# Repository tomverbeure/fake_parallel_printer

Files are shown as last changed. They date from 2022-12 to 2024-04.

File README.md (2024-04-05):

# Fake Parallel Printer

This repo contains the design files for the Fake Printer tool: a hardware
dongle with a DB-25 connector that plugs into the parallel printer port
that was available on nearly all computers and equipment in the eighties
and nineties.

Check out this blog post for a detailed description of the design,
and build and usage instructions:

* [Fake Parallel Printer - A Parallel Port Traffic Capturing Tool](https://tomverbeure.github.io/2023/01/24/Fake-Parallel-Printer-Capture-Tool-HW.html)

There are 2 versions of the PCB. Revision 2 only uses 2 layers and doesn't
stick out as much out of the device in which is plugged in. It's probably
the best one to build. The firmware is designed to work for both PCB versions.

## PCB v1

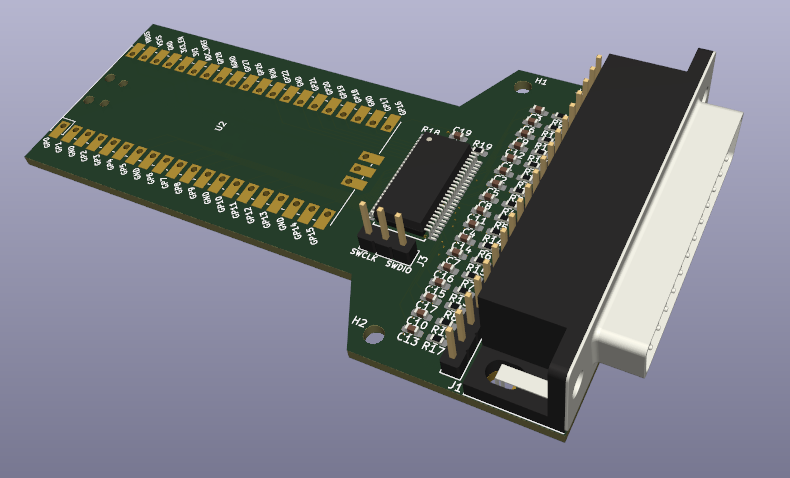
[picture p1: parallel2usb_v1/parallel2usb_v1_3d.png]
3D render of PCB v1


* KiCAD database of the PCB: [`./parallel2usb_v1`](./parallel2usb_v1)
* [Schematic of PCB v1](./parallel2usb_v1/parallel2usb_v1_schematic.pdf)

## PCB v2

**WARNING: v2 hasn't been tested!!!**

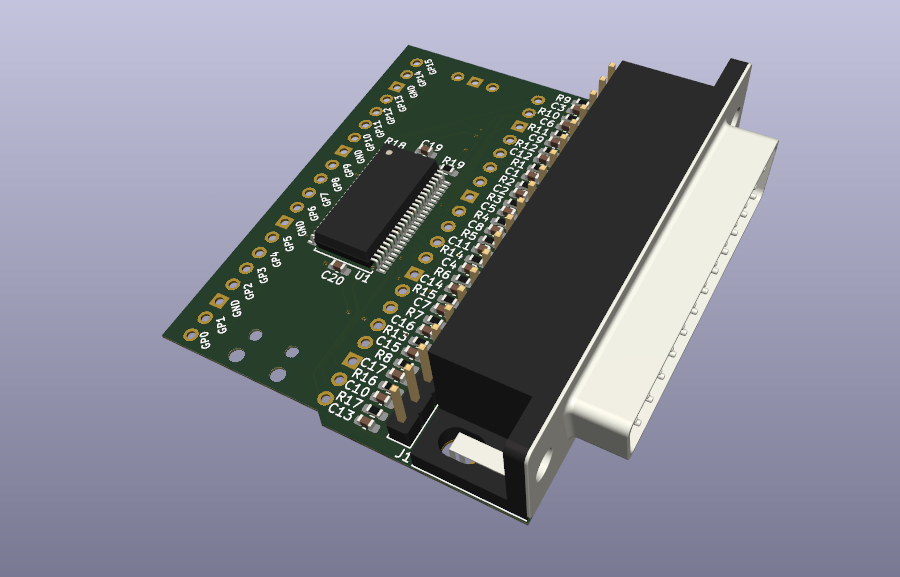
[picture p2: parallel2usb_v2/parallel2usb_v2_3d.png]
3D render of PCB v2


* KiCAD database of the PCB: [`./parallel2usb_v2`](./parallel2usb_v2)
* [Schematic of PCB v2](./parallel2usb_v2/parallel2usb_v2_schematic.pdf)

A Digikey cart with all the components to populate version 2 of the PCB can
be found [here](https://www.digikey.com/short/mcb8vf27). Not all
resistors and capacitor must be populated though. Check out the blog
post for details.

## Firmware

[`parallel2usb_hd_on.uf2`](parallel2usb_hd_on.uf2) contains the compiled
firmware for the Raspberry Pico.

To make changes and recompile yourself:

* set the `PICO_SDK` environment variable to the path of your locally installed 
  [Raspberry Pico SDK](https://github.com/raspberrypi/pico-sdk).
* Build the code:

      mkdir -p ./c/build
      cd ./c/build
      cmake ..
      make

* If all goes well, a new `parallel2usb.uf2` will be waiting in
  `./c/build/parallel2usb`.

## Capturing Parallel Port Data

* Plug in the board into the host with the parallel port.
* Connect your PC to the board with a USB cable.
* Run `python3 ./fake_printer.py -p <USB serial device>` (Use -h for more options.)
* Issue a print operation on the host.
* A new file will be generated for each print operation

## Converting a Parallel Port Captured File

* PCL: use [Ghostscript](https://ghostscript.com/releases/gpcldnld.html)

    `~/tools/ghostpcl-10.0.0-linux-x86_64/gpcl6-1000-linux-x86_64 -dNOPAUSE -sOutputFile=output.png -sDEVICE=png256 -g8000x8000 -r600x600 print_cap.pcl`

* Epson ESC/P: use [PrinterToPDF](https://github.com/RWAP/PrinterToPDF)

    `/opt/printerToPDF/bin/printerToPDF -o output -f /opt/printerToPDF/lib/PrinterToPDF/font2/Epson-Standard.C16 print_cap.esc_p`

* Encapsulated Postscript: use Ghostscript and ImageMagick to add a background if necessary.  Note that some scopes (TDS 684B) may emit a few chunks of comments that `fake_printer.py` will get with multiple-second delays, and they need to be concatenated together to form a valid `eps` file.

    `gs -dSAFER -dBATCH -dNOPAUSE -dEPSCrop -sDEVICE=pngalpha -r300 -sOutputFile=ph1-zoomout.png ph1-zoomout.eps; convert -background black -alpha remove -alpha off ph1-zoomout.png ph1-zoomout.png`

# Conversions

* HP Infinium

```
./fake_printer.py --port=/dev/ttyACM0 -t 2 -v --prefix=hp_osc_ -s eps
inkscape -f ./hp_osc_0.eps -w 1580 -y=255 -e hp_osc_0.png
convert hp_osc_0.png -crop 1294x971+142+80 hp_osc_0_cropped.png
```

* Advantest R3273

    * Config printer: Config -> Copy Config -> Printer: 

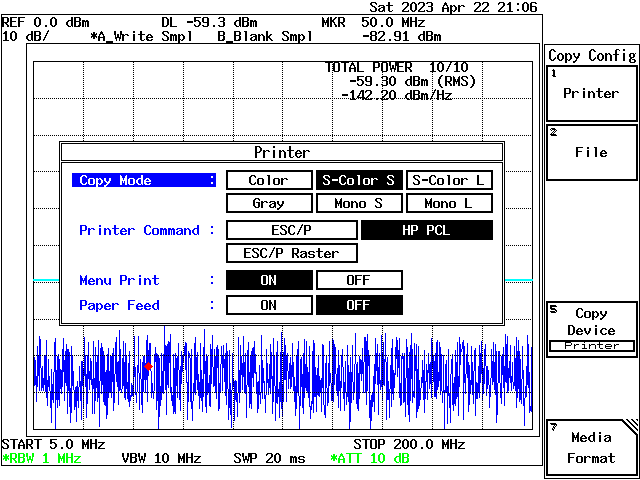
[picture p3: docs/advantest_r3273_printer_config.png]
Advantest R3273 printer config screen
        

    * To print: Copy
    * To convert:

```
./fake_printer.py --port=/dev/ttyACM0 -t 2 -v --prefix=r3273_ -s pcl
~/tools/ghostpcl-10.0.0-linux-x86_64/gpcl6-1000-linux-x86_64 -dNOPAUSE -sOutputFile=test.png -sDEVICE=png256 -g8000x8000 -r600x600 r3273_0.pcl
convert test.png -filter point -resize 2000  test2.png
convert test2.png -crop 640x480+315+94 test3.png
```

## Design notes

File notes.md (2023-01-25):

# Notes

Stuff that needs to be cleaned up...

## Conversion TDS 420A - Encapsulated PostScript

* TDS 420A EPS-Color: [shift-hardcopy] 

    * Capture
     
        `(stty -echo raw; cat > screenshot.eps) < /dev/ttyACM0`

    * Settings
        * Format: EPS Color
        * Layout: Portrait (Yes! NOT landscape!)
        * Port: Centronics
    * Conversion: 

        `inkscape -f ./screenshot.eps -w 1280 -y=255 -e screenshot.png`

        If rotated because landscape was selected:

        `inkscape -f ./screenshot.eps -h 1280 -y=255 -e - | convert - -rotate 90  screenshot.png`

* TDS 420A EPS Mono Image: [shift-hardcopy] 

    * Capture

        `(stty -echo raw; cat > screenshot.eps) < /dev/ttyACM0`

    * Settings
        * Format: EPS Mono Image
        * Layout: Portrait 
        * Port: Centronics
    * Conversion

        `inkscape -f ./screenshot.eps -w 1280 -y=255 -e screenshot.png`

* Conversion TDS 420A - Epson

    * Capture

        `(stty -echo raw; cat > screenshot.epson) < /dev/ttyACM0`

    * Settings:
        * Format: Epson - 9 & 24 pin dot matrix printer
        * Layout: Landscape 
        * Port: Centronics
    * Typical capture file size: ~39KB
    * Conversion 

        `/opt/printerToPDF/bin/printerToPDF -o output -f /opt/printerToPDF/lib/PrinterToPDF/font2/Epson-Standard.C16 screenshot.epson`

# Advantest PCL to PDF

* [Ghostscript](https://ghostscript.com/releases/gpcldnld.html)

    `~/tools/ghostpcl-10.0.0-linux-x86_64/gpcl6-1000-linux-x86_64 -dNOPAUSE -sOutputFile=test.png -sDEVICE=png256 -g2000x1500 -r300x300  sa_pcl_s_color_s_a.pcl`

    Best result so far:

    `~/tools/ghostpcl-10.0.0-linux-x86_64/gpcl6-1000-linux-x86_64 -dNOPAUSE -sOutputFile=test.png -sDEVICE=png256 -g8000x8000 -r600x600 sa_pcl_s_color_s_a.pcl`

    `convert test.png -filter point -resize 2000  test2.png`

* [PrinterToPDF](https://github.com/tomverbeure/PrinterToPDF)

    `/opt/printerToPDF/bin/printerToPDF -o output -f /opt/printerToPDF/lib/PrinterToPDF/font2/Epson-Standard.C16  dump.epson`

# Misc

* [Tweet by Sell My Retro](https://twitter.com/SellMyRetro/status/1614215674024398848)

# CircuitPython

* Download UF2: https://circuitpython.org/board/raspberry_pi_pico/
* Terminal: `picocom /dev/ttyACM0`

    Gives a command line

    Ctrl-A Ctrl-X to exit picocom

* Copy `code.py` to CIRCUITPY drive and power cycle -> your code will run

# Protocol Compatibility mode

host to device:

* nINIT: pulsed low to reset device.
* nSELIN: driven low by host to activate the device
* nAUTOF: driven low by host to enable auto-line feed. Ignore?

* nSTROBE: set low by host when data is valid. Used to store data into an latch
* D[7:0]: data must be stable as long as nSTROBE is low

device to host:

* nACK: Pulsed low by device to acknowledge received of data. Length of pulse?
    150kB/s -> 6uS is upper bound length. Let's do 2uS.
* BUSY: driven high by device to indicate that device is not ready. 
* nERROR: driven low by device to indicate an error.
* SEL: driven high by device to indicate that device is present.
* PE (Paper Error): driven high by device to indicate a paper error

# References

* [Parallel-Port Interface Powers Low Voltage Systems](https://www.analog.com/en/design-notes/parallelport-interface-powers-low-voltage-systems.html)

    Not useful: voltage regulator only goes up to +2V.

    * [Maxim MAX1841 datasheet](https://www.mouser.com/datasheet/2/256/MAX1840-MAX1841-1308121.pdf)

* [Arduino: Read data from parallel port](https://forum.arduino.cc/t/read-data-from-parallel-port/105648/15)

 * [Rue's Parallel2Serial](https://github.com/ruenahcmohr/Parallel2Serial)

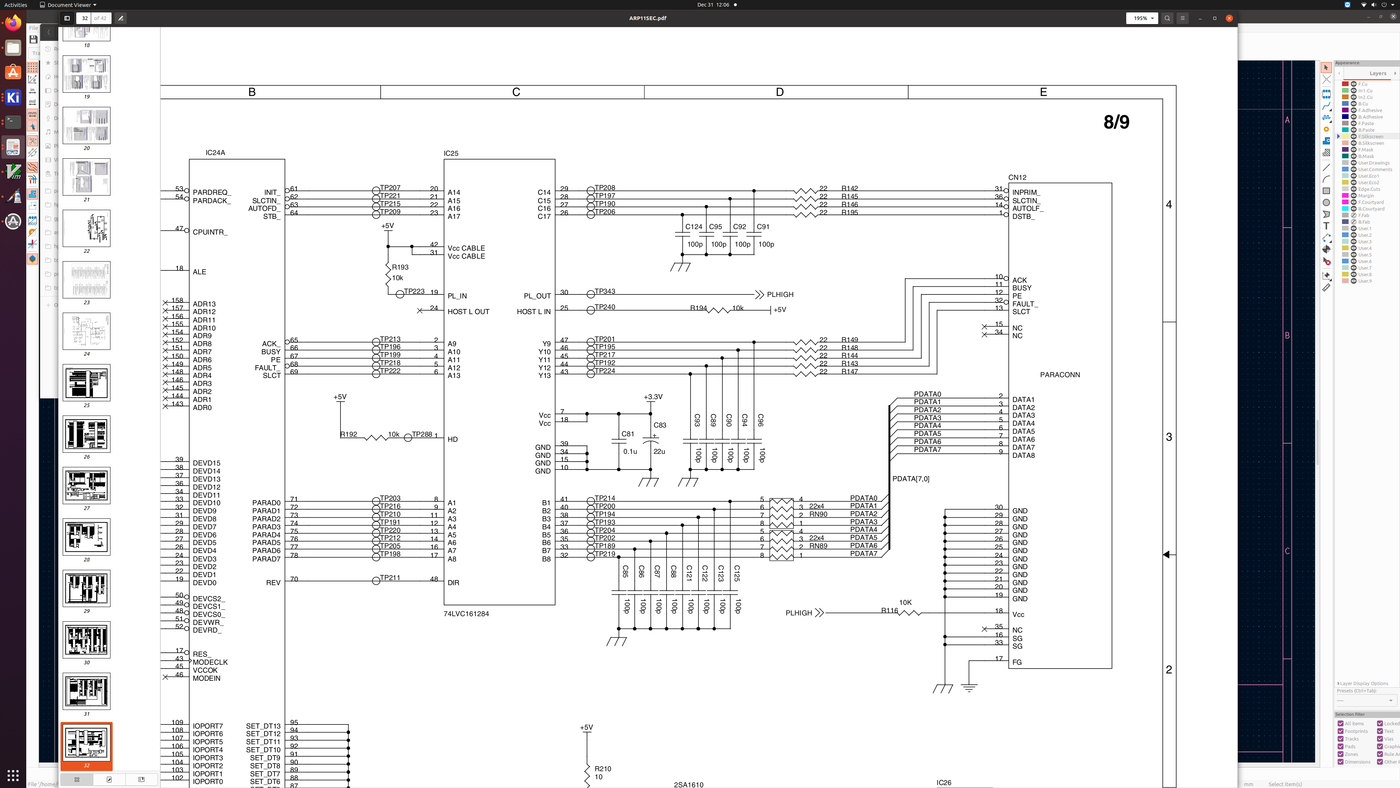
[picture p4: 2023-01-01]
docs/74LVC161284_schematic.png

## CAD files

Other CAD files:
parallel2usb_v1/KiCad-RP-Pico/SketchUp Model/Pico.skp
parallel2usb_v2/KiCad-RP-Pico/SketchUp Model/Pico.skp

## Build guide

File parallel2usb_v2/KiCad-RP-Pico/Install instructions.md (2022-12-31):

# Install instructions

## 1. Copy the files locally

Copy the `RP-Pico Libraries` folder wherever you like on your computer.

## 2. Install the Raspberry Pi Pico board schema symbol

Use the `KiCad | Preferences | Manage Symbol Libraries...` command to manage the symbol library:



then select the global tab and click on the folder button:



navigate to the `RP-Pico Libraries` folder, select the `MCU_RaspberryPi_and_Boards.kicad_sym` file and open it:



et voilà, the first step is completed:



You can now close the symbol libraries manager window.

## 3. Install the Raspberry Pi Pico board footprint

You can use a similar approach to add the footprint to the footprint libraries manager, but I've found some issues that I've solved using the footprint editor, so here are the steps I suggest you to follow:

Open the footprint editor



wait for the footprints to load... then use the `File | Add Library` command:



confirm the `Global` choice:



and select the `MCU_RaspberriPi_and_Boards.pretty` folder (yes, the folder represent a footprint library on KiCad):



Now the library is installed on KiCad with the Raspberry Pi Pico footprint (double click on it to see it on the editor pane):



Don't close the windows as the next step start from here.

## 4. Install the Raspberry Pi Pico board footprint 3D visual

If not already open, open the the footprint editor

symbol library manager

double click on the `RPi_Pico_SMD_TH` footprint from the `MCU_RaspberriPi_and_Boards` library and then click on the `Footprint properties` icon:



In the footprint properties window, first select the `3D Settings` tab. Please note that the preview shows only the PCB board with the footprint added on step 3, without any 3D representation of the Raspberry Pi Pico board. Now click on the folder icon to add the 3D model:



Navigate to the `RP-Pico Libraries` folder, select the `Pico.wrl` file and wait until the model is shown in the right panel, then confirm with OK:



The model is already scaled and translated to match the footprint:



now close the `Footprint Properties` window, and the `Footprint Editor`, obviously saving the changes.

## Conclusion

Now that you've installed the schema and footprint and added the 3D model to the footprint, you can use the Raspberry Pi Pico board on your KiCad projects.

I've also added a test KiCad Project on the `Test` folder, that you can use to see an example of it.

Have fun!

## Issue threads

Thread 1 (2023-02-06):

Well done!  and a license question?

RobTillaart, 2023-02-06:
Hi Tom,

Saw a reference to your project on HackaDay and I love it, well done!

Writing (Arduino) libraries is one of my jobs and I want to make a reference to your project in my Parallel Printer library. (OK?)
- https://github.com/RobTillaart/ParallelPrinter

It is the other side of your project - think of a driver - to be able to use old printers as an output device.
In fact the project you made is on my todo list. (maybe it will drop off ;)

Question: you do not have a license set with your project, is this on purpose or?

tomverbeure, 2023-02-06:
Hi Rob,

Feel free to use this any way you want!

I've added a license.

Tom

Closed 2023-02-06.

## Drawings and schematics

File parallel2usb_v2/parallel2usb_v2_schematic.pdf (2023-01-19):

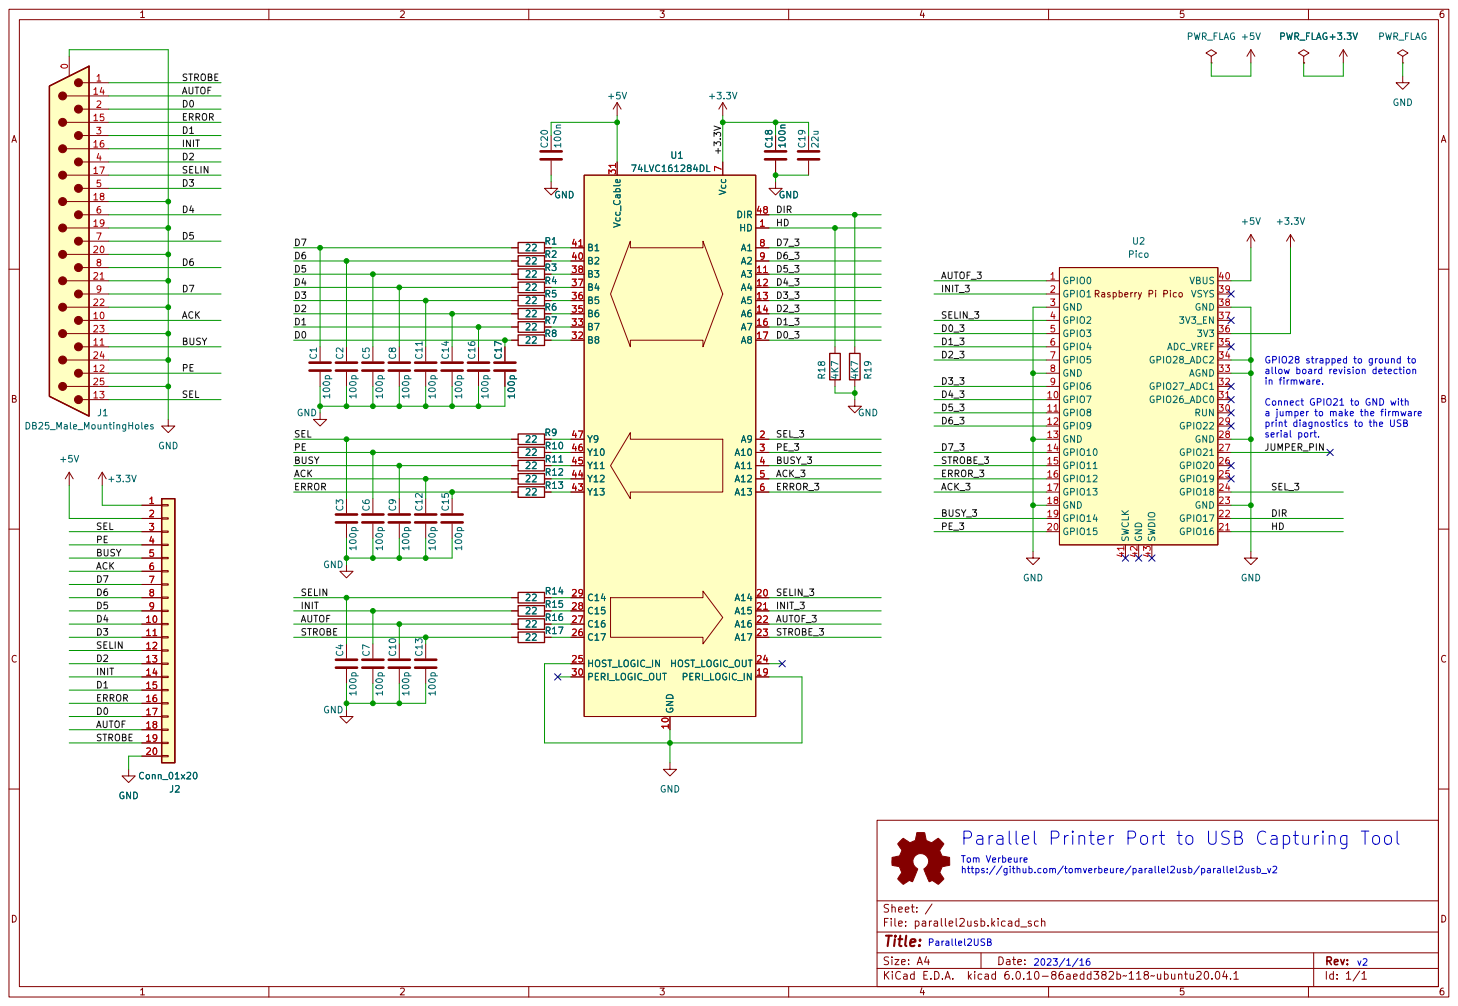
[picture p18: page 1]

GPIO28 strapped to ground to
allow board revision detection
in firmware.

print diagnostics to the USB
serial port.
JUMPER_PIN

https://github.com/tomverbeure/parallel2usb/parallel2usb_v2 R11

2023/1/16 Parallel Printer Port to USB Capturing Tool Tom Verbeure

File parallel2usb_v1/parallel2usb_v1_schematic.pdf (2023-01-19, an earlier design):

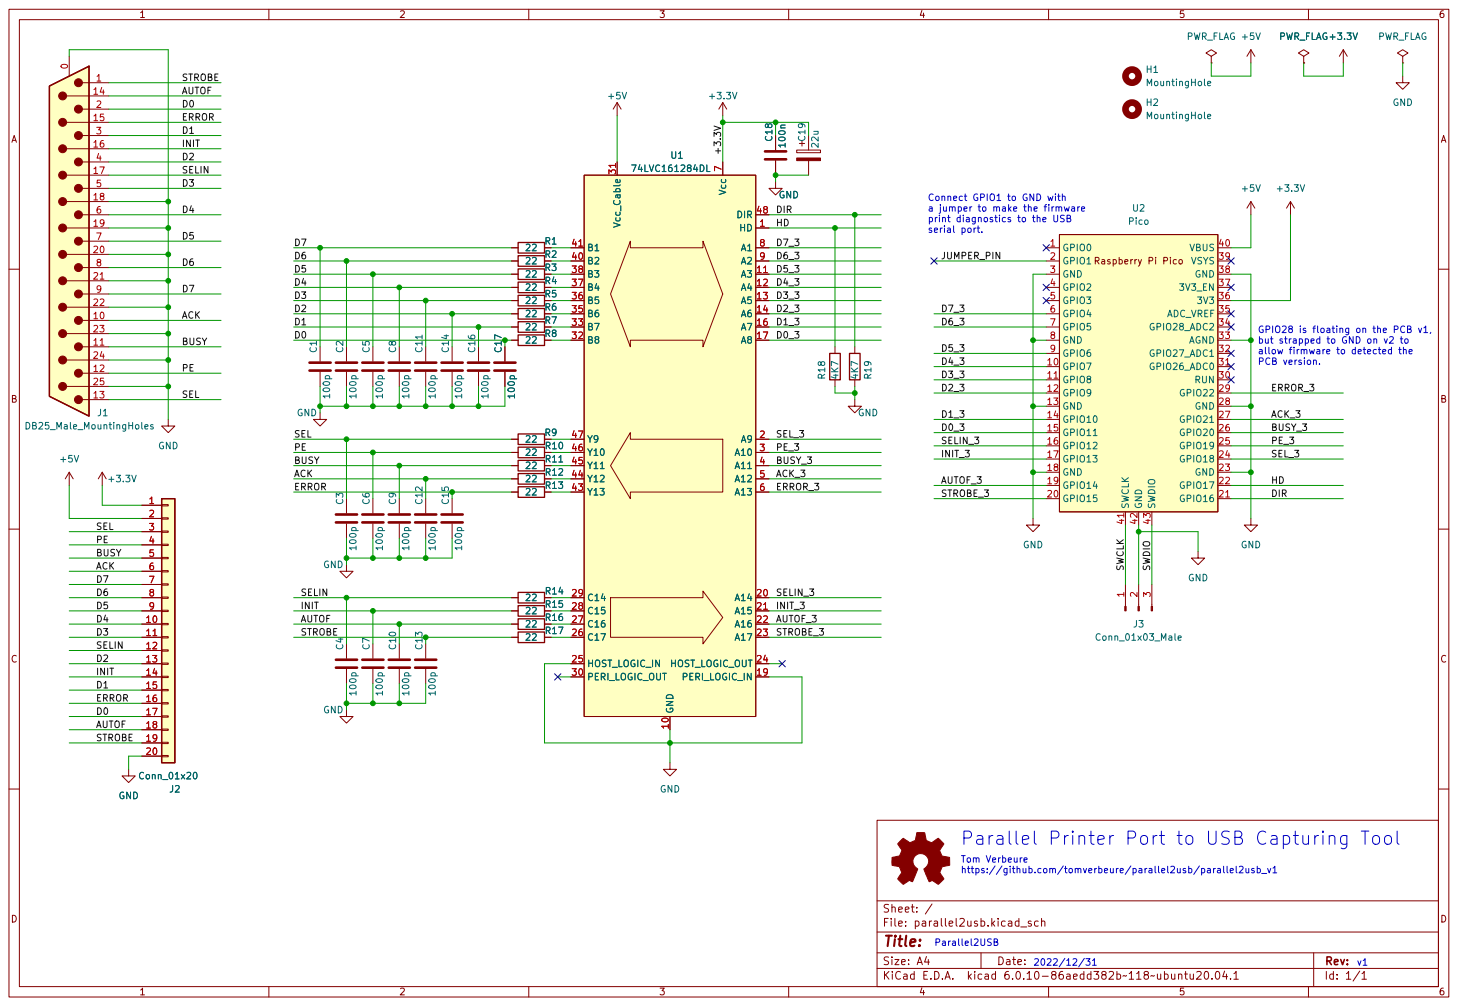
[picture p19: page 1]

Connect GPIO1 to GND with
a jumper to make the firmware
print diagnostics to the USB
serial port.

but strapped to GND on v2 to allow firmware to detected the PCB version. Parallel Printer Port to USB Capturing Tool

Tom Verbeure
https://github.com/tomverbeure/parallel2usb/parallel2usb_v1

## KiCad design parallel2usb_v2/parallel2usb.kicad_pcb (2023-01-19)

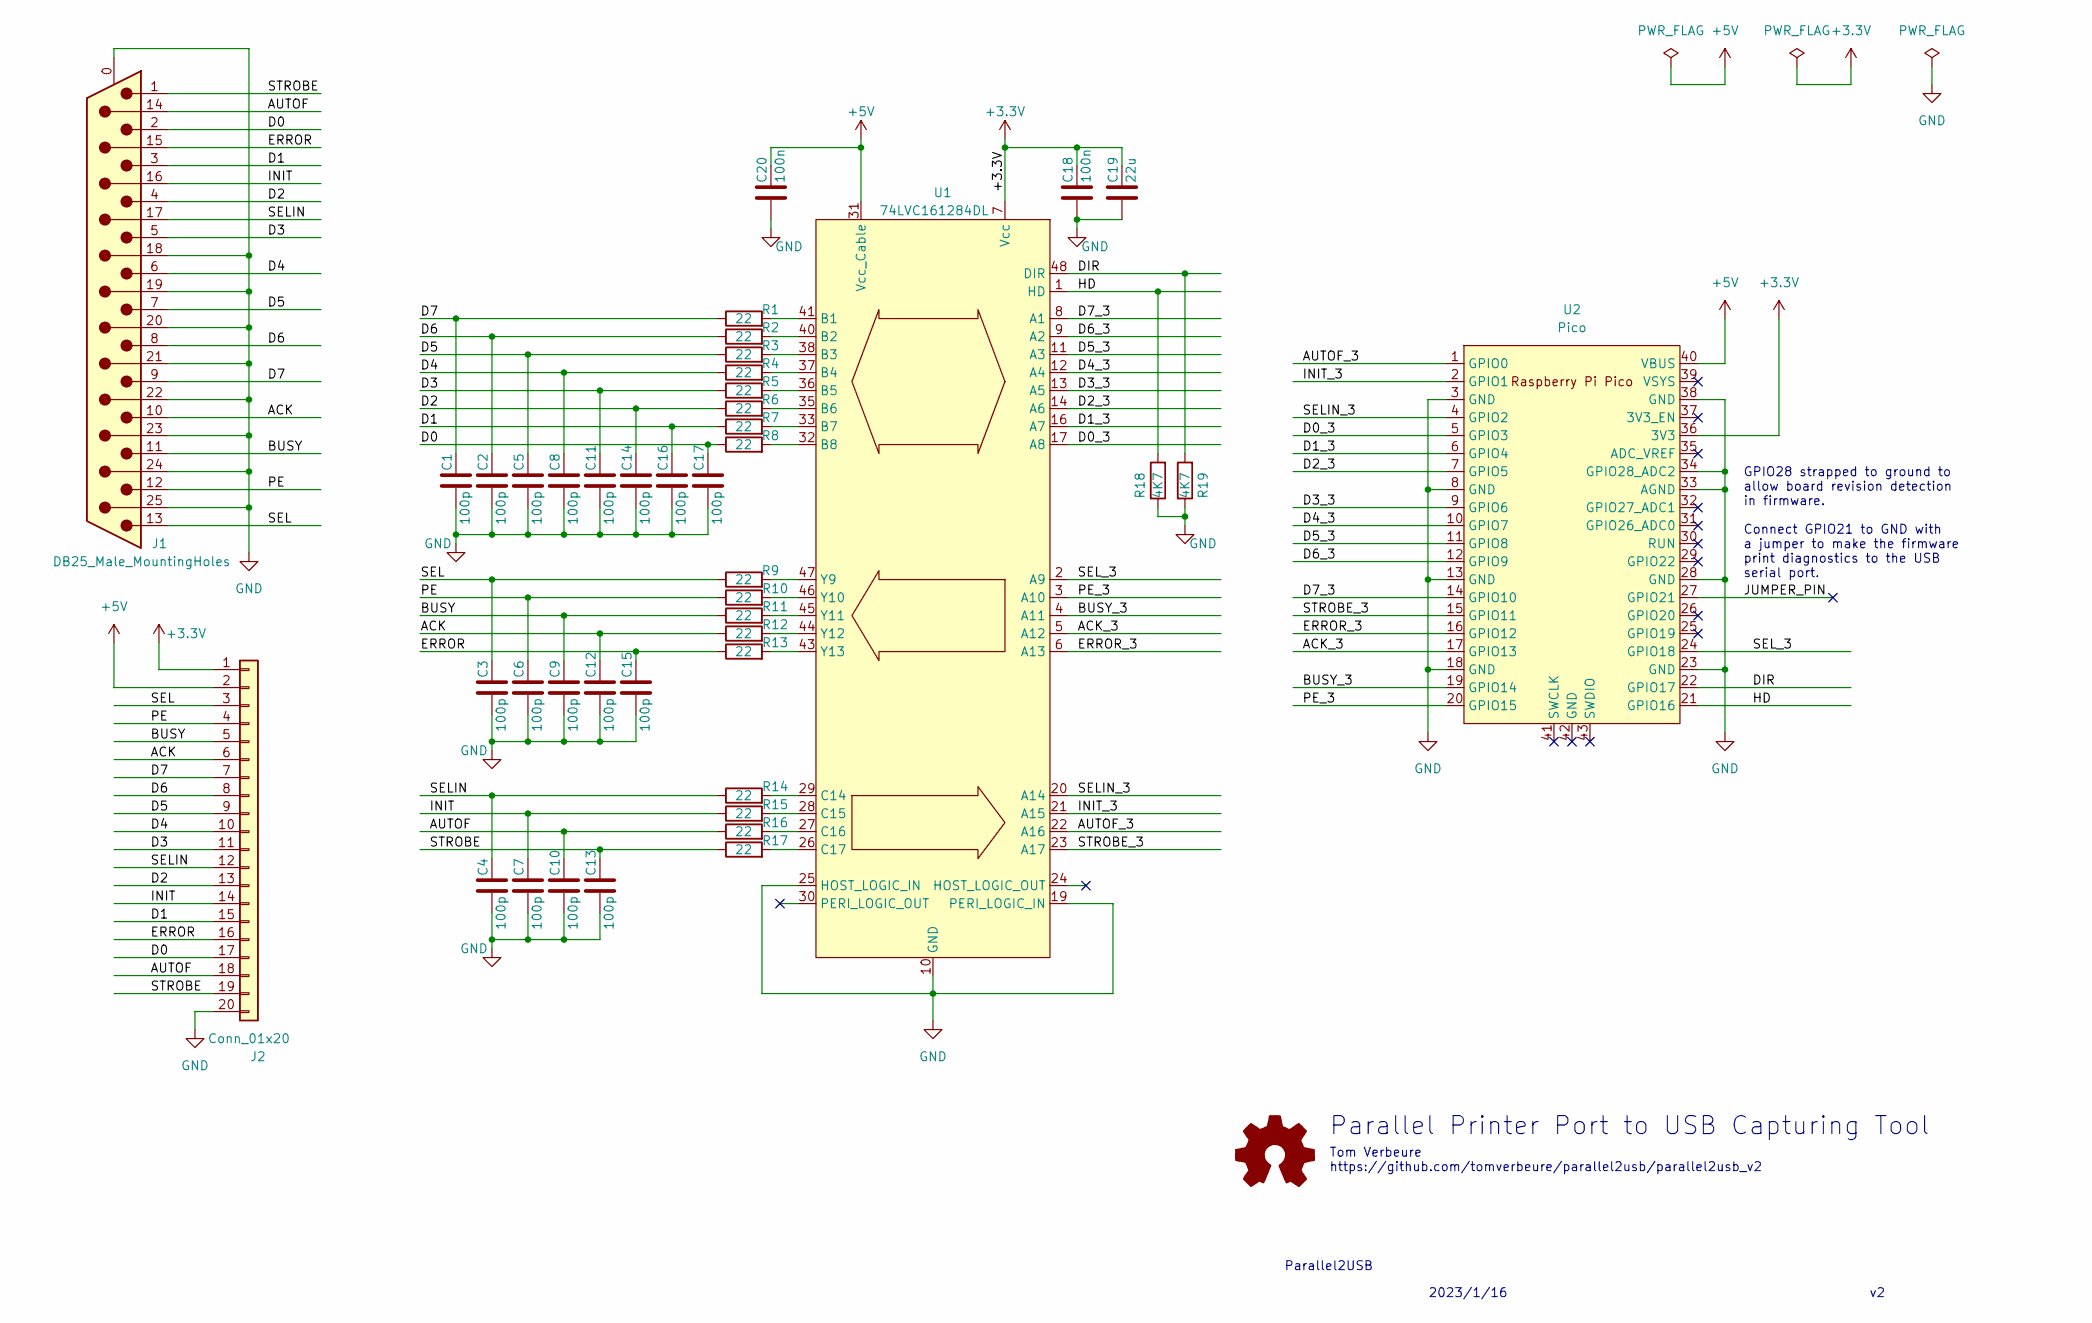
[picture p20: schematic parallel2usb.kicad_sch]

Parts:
C1, C2, C3, C4, C5, C6, C7, C8, C9, C10, C11, C12, C13, C14, C15, C16, C17: 100p; C_0603_1608Metric_Pad1.08x0.95mm_HandSolder
C18, C20: 100n; C_0603_1608Metric_Pad1.08x0.95mm_HandSolder
C19: 22u; C_0603_1608Metric_Pad1.08x0.95mm_HandSolder
J1: DB25_Male_MountingHoles; DSUB-25_Male_Horizontal_P2.77x2.84mm_EdgePinOffset7.70mm_Ho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
J2: Conn_01x20; PinHeader_1x20_P2.54mm_Vertical
R1, R2, R3, R4, R5, R6, R7, R8, R9, R10, R11, R12, R13, R14, R15, R16, R17: 22; R_0603_1608Metric_Pad0.98x0.95mm_HandSolder
R18, R19: 4K7; R_0603_1608Metric_Pad0.98x0.95mm_HandSolder
U1: 74LVC161284DL; SSOP-48_7.5x15.9mm_P0.635mm
U2: Pico; RPi_Pico_SMD_TH

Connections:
+3.3V: C18.1, C19.1, J2.1, U1.7 (Vcc), U1.18 (Vcc), U2.36 (3V3)
+5V: C20.1, J2.2, U1.31 (Vcc_Cable), U1.42 (Vcc_Cable), U2.40 (VBUS)
/ACK: C12.1, J1.10, J2.6, R12.1
/ACK_3: U1.5 (A12), U2.17 (GPIO13)
/AUTOF: C10.1, J1.14, J2.18, R16.1
/AUTOF_3: U1.22 (A16), U2.1 (GPIO0)
/BUSY: C9.1, J1.11, J2.5, R11.1
/BUSY_3: U1.4 (A11), U2.19 (GPIO14)
/D0: C17.1, J1.2, J2.17, R8.1
/D0_3: U1.17 (A8), U2.5 (GPIO3)
/D1: C16.1, J1.3, J2.15, R7.1
/D1_3: U1.16 (A7), U2.6 (GPIO4)
/D2: C14.1, J1.4, J2.13, R6.1
/D2_3: U1.14 (A6), U2.7 (GPIO5)
/D3: C11.1, J1.5, J2.11, R5.1
/D3_3: U1.13 (A5), U2.9 (GPIO6)
/D4: C8.1, J1.6, J2.10, R4.1
/D4_3: U1.12 (A4), U2.10 (GPIO7)
/D5: C5.1, J1.7, J2.9, R3.1
/D5_3: U1.11 (A3), U2.11 (GPIO8)
/D6: C2.1, J1.8, J2.8, R2.1
/D6_3: U1.9 (A2), U2.12 (GPIO9)
/D7: C1.1, J1.9, J2.7, R1.1
/D7_3: U1.8 (A1), U2.14 (GPIO10)
/DIR: R19.2, U1.48 (DIR), U2.22 (GPIO17)
/ERROR: C15.1, J1.15, J2.16, R13.1
/ERROR_3: U1.6 (A13), U2.16 (GPIO12)
/HD: R18.2, U1.1 (HD), U2.21 (GPIO16)
/INIT: C7.1, J1.16, J2.14, R15.1
/INIT_3: U1.21 (A15), U2.2 (GPIO1)
/JUMPER_PIN: U2.27 (GPIO21)
/PE: C6.1, J1.12, J2.4, R10.1
/PE_3: U1.3 (A10), U2.20 (GPIO15)
/SEL: C3.1, J1.13, J2.3, R9.1
/SELIN: C4.1, J1.17, J2.12, R14.1
/SELIN_3: U1.20 (A14), U2.4 (GPIO2)
/SEL_3: U1.2 (A9), U2.24 (GPIO18)
/STROBE: C13.1, J1.1, J2.19, R17.1
/STROBE_3: U1.23 (A17), U2.15 (GPIO11)
GND: C1.2, C2.2, C3.2, C4.2, C5.2, C6.2, C7.2, C8.2, C9.2, C10.2, C11.2, C12.2, C13.2, C14.2, C15.2, C16.2, C17.2, C18.2, C19.2, C20.2, J1.0 (PAD), J1.18, J1.19, J1.20, J1.21, J1.22, J1.23, J1.24, J1.25, J2.20, R18.1, R19.1, U1.10 (GND), U1.15 (GND), U1.19 (PERI_LOGIC_IN), U1.25 (HOST_LOGIC_IN), U1.34 (GND), U1.39 (GND), U2.3 (GND), U2.8 (GND), U2.13 (GND), U2.18 (GND), U2.23 (GND), U2.28 (GND), U2.33 (AGND), U2.34 (GPIO28_ADC2), U2.38 (GND)
unnamed: R1.2, U1.41 (B1)
unnamed: R2.2, U1.40 (B2)
unnamed: R3.2, U1.38 (B3)
unnamed: R4.2, U1.37 (B4)
unnamed: R5.2, U1.36 (B5)
unnamed: R6.2, U1.35 (B6)
unnamed: R7.2, U1.33 (B7)
unnamed: R8.2, U1.32 (B8)
unnamed: R9.2, U1.47 (Y9)
unnamed: R10.2, U1.46 (Y10)
unnamed: R11.2, U1.45 (Y11)
unnamed: R12.2, U1.44 (Y12)
unnamed: R13.2, U1.43 (Y13)
unnamed: R14.2, U1.29 (C14)
unnamed: R15.2, U1.28 (C15)
unnamed: R16.2, U1.27 (C16)
unnamed: R17.2, U1.26 (C17)

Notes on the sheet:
Parallel2USB
2023/1/16
Connect GPIO21 to GND with a jumper to make the firmware print diagnostics to the USB serial port.
GPIO28 strapped to ground to allow board revision detection in firmware.
Tom Verbeure https://github.com/tomverbeure/parallel2usb/parallel2usb_v2
Parallel Printer Port to USB Capturing Tool

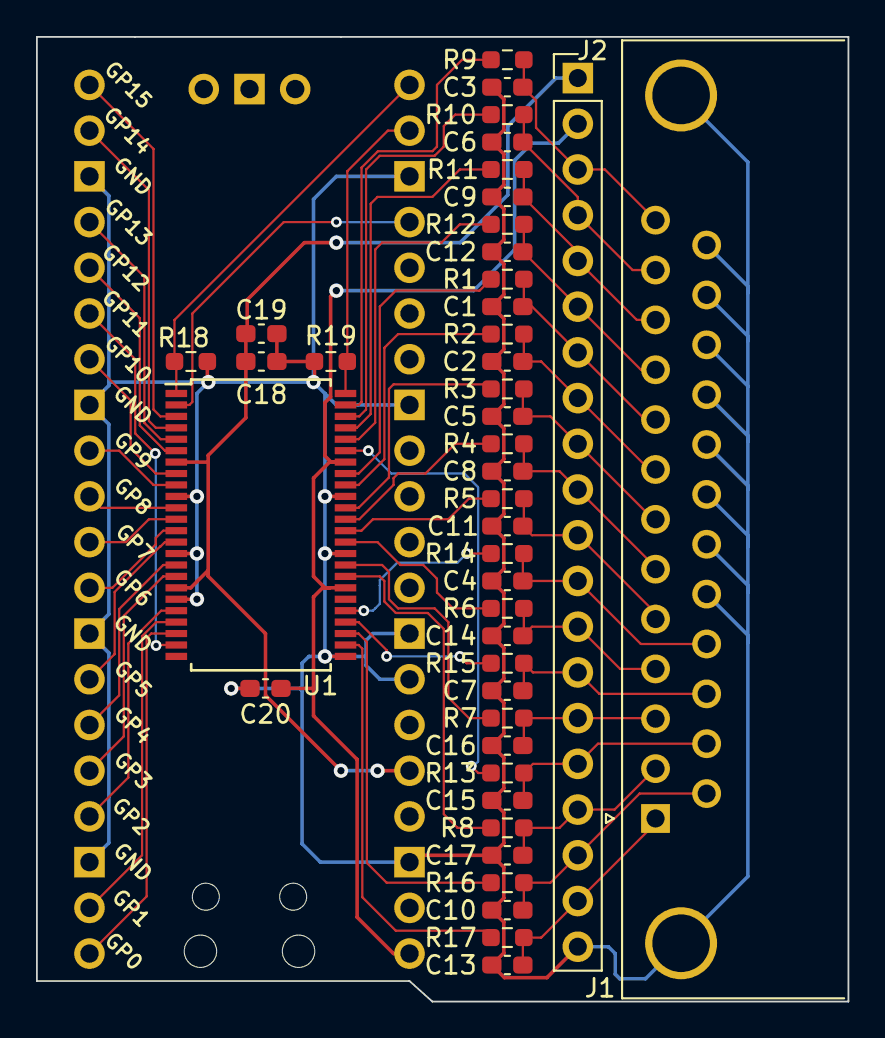
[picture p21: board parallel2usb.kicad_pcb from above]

Board: 2 copper layers, 45.1 x 53.6 mm, 43 parts (1 on the bottom side), 56 nets.

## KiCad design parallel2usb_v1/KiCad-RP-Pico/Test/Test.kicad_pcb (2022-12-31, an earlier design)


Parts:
J1, J2: Conn_01x20; PinSocket_1x20_P1.00mm_Vertical
J3: Conn_01x03; PinSocket_1x03_P1.00mm_Vertical
U1: Pico; RPi_Pico_SMD_TH

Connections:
GND: J1.3, J1.8, J1.13, J1.18, J2.3, J2.13, J2.18, J3.2, U1.3 (GND), U1.8 (GND), U1.13 (GND), U1.18 (GND), U1.23 (GND), U1.28 (GND), U1.38 (GND), U1.42 (GND)
unnamed: J1.1, U1.1 (GPIO0)
unnamed: J1.2, U1.2 (GPIO1)
unnamed: J1.4, U1.4 (GPIO2)
unnamed: J1.5, U1.5 (GPIO3)
unnamed: J1.6, U1.6 (GPIO4)
unnamed: J1.7, U1.7 (GPIO5)
unnamed: J1.9, U1.9 (GPIO6)
unnamed: J1.10, U1.10 (GPIO7)
unnamed: J1.11, U1.11 (GPIO8)
unnamed: J1.12, U1.12 (GPIO9)
unnamed: J1.14, U1.14 (GPIO10)
unnamed: J1.15, U1.15 (GPIO11)
unnamed: J1.16, U1.16 (GPIO12)
unnamed: J1.17, U1.17 (GPIO13)
unnamed: J1.19, U1.19 (GPIO14)
unnamed: J1.20, U1.20 (GPIO15)
unnamed: J2.1, U1.40 (VBUS)
unnamed: J2.2, U1.39 (VSYS)
unnamed: J2.4, U1.37 (3V3_EN)
unnamed: J2.5, U1.36 (3V3)
unnamed: J2.6, U1.35 (ADC_VREF)
unnamed: J2.7, U1.34 (GPIO28_ADC2)
unnamed: J2.8, U1.33 (AGND)
unnamed: J2.9, U1.32 (GPIO27_ADC1)
unnamed: J2.10, U1.31 (GPIO26_ADC0)
unnamed: J2.11, U1.30 (RUN)
unnamed: J2.12, U1.29 (GPIO22)
unnamed: J2.14, U1.27 (GPIO21)
unnamed: J2.15, U1.26 (GPIO20)
unnamed: J2.16, U1.25 (GPIO19)
unnamed: J2.17, U1.24 (GPIO18)
unnamed: J2.19, U1.22 (GPIO17)
unnamed: J2.20, U1.21 (GPIO16)
unnamed: J3.1, U1.43 (SWDIO)
unnamed: J3.3, U1.41 (SWCLK)


Board: 2 copper layers, 43.0 x 65.0 mm, 4 parts (0 on the bottom side), 36 nets.

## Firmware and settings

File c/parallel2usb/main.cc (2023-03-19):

#include <stdio.h>
#include <stdlib.h>
#include <stdint.h>
#include <math.h>

#include "pico/stdlib.h"
#include "pico/multicore.h"

#include "hardware/clocks.h"

#define ACK_DURATION_US         2

// Pins are defined in
// .../pico-sdk/src/boards/include/boards/pico.h
#define LED_PIN         PICO_DEFAULT_LED_PIN

#define REV_PIN         28

#define JUMPER_PIN_V1   1
#define JUMPER_PIN_V2   21

//============================================================
// 74LVC161284 control
//============================================================

// HD
// 1 -> totempole output high drive
// 0 -> pullup high drive
// A value of 1 will result in much faster rising edges of BUSY and nACK.
#define HD_PIN_V1       17  
#define HD_PIN_V2       16  

#define HD_PULLUP       0 
#define HD_HIGH_DRIVE   1 

// DIR=0 -> data from host to device. 1 -> from device to host
#define DIR_PIN_V1      16
#define DIR_PIN_V2      17

#define DIR_HOST_TO_PRINTER     0
#define DIR_PRINTER_TO_HOST     1

//============================================================
// Host to device 
//============================================================

#define nSTROBE_PIN_V1  15
#define nAUTOF_PIN_V1   14
#define nINIT_PIN_V1    13
#define nSELIN_PIN_V1   12

#define nSTROBE_PIN_V2  11
#define nAUTOF_PIN_V2   0
#define nINIT_PIN_V2    1
#define nSELIN_PIN_V2   2

#define D0_PIN_V1       11
#define D1_PIN_V1       10
#define D2_PIN_V1       9
#define D3_PIN_V1       8
#define D4_PIN_V1       7
#define D5_PIN_V1       6
#define D6_PIN_V1       5
#define D7_PIN_V1       4

#define D0_PIN_V2       3
#define D1_PIN_V2       4
#define D2_PIN_V2       5
#define D3_PIN_V2       6
#define D4_PIN_V2       7
#define D5_PIN_V2       8
#define D6_PIN_V2       9
#define D7_PIN_V2       10

//============================================================
// Device to host
//============================================================

#define nERROR_PIN_V1   22
#define nACK_PIN_V1     21
#define BUSY_PIN_V1     20
#define PE_PIN_V1       19
#define SEL_PIN_V1      18

#define nERROR_PIN_V2   12
#define nACK_PIN_V2     13
#define BUSY_PIN_V2     14
#define PE_PIN_V2       15
#define SEL_PIN_V2      18

//============================================================
// Debug pins
//============================================================

#define DEBUG0_PIN      26
#define DEBUG1_PIN      27
#define DEBUG2_PIN      28

int board_rev;

int jumper_pin;

int dir_pin;
int hd_pin;

int n_strobe_pin;
int n_autof_pin;
int n_init_pin;
int n_selin_pin;

int d0_pin;
int d1_pin;
int d2_pin;
int d3_pin;
int d4_pin;
int d5_pin;
int d6_pin;
int d7_pin;

int n_error_pin;
int n_ack_pin;
int busy_pin;
int pe_pin;
int sel_pin;


void setup_ios()
{
    // The REV pin (GPIO28) is used to differentiate between revision
    // 1 and 2 of the PCB. 
    // Revision 1 of the PCB has this pin floating while revision 2 has
    // it strapped to ground. If we enable the pullup on this GPIO,
    // this pin will read back a logic value of 1 for revision 1 and a
    // value of 0 for revision 2.
    gpio_init(REV_PIN); 
    gpio_set_dir(REV_PIN, GPIO_IN);
    sleep_us(10);
    gpio_pull_up(REV_PIN);

    board_rev = gpio_get(REV_PIN) == 1 ? 1 : 2;

    // Assign pin function to pin number based on board revision.
    jumper_pin    = board_rev == 1 ? JUMPER_PIN_V1  : JUMPER_PIN_V2; 

    dir_pin       = board_rev == 1 ? DIR_PIN_V1     : DIR_PIN_V2; 
    hd_pin        = board_rev == 1 ? HD_PIN_V1      : HD_PIN_V2; 

    d0_pin        = board_rev == 1 ? D0_PIN_V1      : D0_PIN_V2;
    d1_pin        = board_rev == 1 ? D1_PIN_V1      : D1_PIN_V2;
    d2_pin        = board_rev == 1 ? D2_PIN_V1      : D2_PIN_V2;
    d3_pin        = board_rev == 1 ? D3_PIN_V1      : D3_PIN_V2;
    d4_pin        = board_rev == 1 ? D4_PIN_V1      : D4_PIN_V2;
    d5_pin        = board_rev == 1 ? D5_PIN_V1      : D5_PIN_V2;
    d6_pin        = board_rev == 1 ? D6_PIN_V1      : D6_PIN_V2;
    d7_pin        = board_rev == 1 ? D7_PIN_V1      : D7_PIN_V2;

    n_strobe_pin  = board_rev == 1 ? nSTROBE_PIN_V1 : nSTROBE_PIN_V2; 
    n_autof_pin   = board_rev == 1 ? nAUTOF_PIN_V1  : nAUTOF_PIN_V2; 
    n_init_pin    = board_rev == 1 ? nINIT_PIN_V1   : nINIT_PIN_V2; 
    n_selin_pin   = board_rev == 1 ? nSELIN_PIN_V1  : nSELIN_PIN_V2; 

    n_error_pin   = board_rev == 1 ? nERROR_PIN_V1  : nERROR_PIN_V2; 
    busy_pin      = board_rev == 1 ? BUSY_PIN_V1    : BUSY_PIN_V2; 
    n_ack_pin     = board_rev == 1 ? nACK_PIN_V1    : nACK_PIN_V2; 
    pe_pin        = board_rev == 1 ? PE_PIN_V1      : PE_PIN_V2; 
    sel_pin       = board_rev == 1 ? SEL_PIN_V1     : SEL_PIN_V2; 

    // Blink LED at bootup. It's just the right thing to do.
    gpio_init(LED_PIN);
    gpio_set_dir(LED_PIN, GPIO_OUT);
    gpio_put(LED_PIN, 1);
    sleep_ms(250);
    gpio_put(LED_PIN, 0);
    sleep_ms(250);
    gpio_put(LED_PIN, 1);

    gpio_init(dir_pin);
    gpio_set_dir(dir_pin, GPIO_OUT);
    gpio_put(dir_pin, DIR_HOST_TO_PRINTER);

    gpio_init(hd_pin);
    gpio_set_dir(hd_pin, GPIO_OUT);
    gpio_put(hd_pin, HD_HIGH_DRIVE);

    gpio_init(jumper_pin);
    gpio_set_dir(jumper_pin, GPIO_IN);
    gpio_pull_up(jumper_pin);

    gpio_init(n_strobe_pin);
    gpio_set_dir(n_strobe_pin, GPIO_IN);

    gpio_init(n_autof_pin);
    gpio_set_dir(n_autof_pin, GPIO_IN);

    gpio_init(n_init_pin);
    gpio_set_dir(n_init_pin, GPIO_IN);

    gpio_init(n_selin_pin);
    gpio_set_dir(n_selin_pin, GPIO_IN);

    gpio_init(d0_pin);
    gpio_init(d1_pin);
    gpio_init(d2_pin);
    gpio_init(d3_pin);
    gpio_init(d4_pin);
    gpio_init(d5_pin);
    gpio_init(d6_pin);
    gpio_init(d7_pin);

    gpio_set_dir(d0_pin, GPIO_IN);
    gpio_set_dir(d1_pin, GPIO_IN);
    gpio_set_dir(d2_pin, GPIO_IN);
    gpio_set_dir(d3_pin, GPIO_IN);
    gpio_set_dir(d4_pin, GPIO_IN);
    gpio_set_dir(d5_pin, GPIO_IN);
    gpio_set_dir(d6_pin, GPIO_IN);
    gpio_set_dir(d7_pin, GPIO_IN);

    gpio_init(n_error_pin);
    gpio_set_dir(n_error_pin, GPIO_OUT);
    gpio_put(n_error_pin, 1);

    gpio_init(n_ack_pin);
    gpio_set_dir(n_ack_pin, GPIO_OUT);
    gpio_put(n_ack_pin, 1);

    gpio_init(busy_pin);
    gpio_set_dir(busy_pin, GPIO_OUT);
    gpio_put(busy_pin, 0);

    gpio_init(pe_pin);
    gpio_set_dir(pe_pin, GPIO_OUT);
    gpio_put(pe_pin, 0);

    gpio_init(sel_pin);
    gpio_set_dir(sel_pin, GPIO_OUT);
    gpio_put(sel_pin, 1);

    gpio_init(DEBUG0_PIN);
    gpio_set_dir(DEBUG0_PIN, GPIO_OUT);
    gpio_put(DEBUG0_PIN, 0);

    gpio_init(DEBUG1_PIN);
    gpio_set_dir(DEBUG1_PIN, GPIO_OUT);
    gpio_put(DEBUG1_PIN, 0);

    gpio_init(DEBUG2_PIN);
    gpio_set_dir(DEBUG2_PIN, GPIO_OUT);
    gpio_put(DEBUG2_PIN, 0);
}

uint8_t get_data()
{
    uint8_t d = (gpio_get(d7_pin)<<7) |
                (gpio_get(d6_pin)<<6) |
                (gpio_get(d5_pin)<<5) |
                (gpio_get(d4_pin)<<4) |
                (gpio_get(d3_pin)<<3) |
                (gpio_get(d2_pin)<<2) |
                (gpio_get(d1_pin)<<1) |
                 gpio_get(d0_pin);

    return d;
}

int nr_bytes = 0;
uint32_t checksum = 0;

// __not_in_flash_func attribute increase the CPU performance
// The goal was to make sure that BUSY could be asserted before nSTROBE gets
// deasserted (which can happen after only 500ns.)
//
// However, testing on my equipment showed that printing works even when you never
// assert BUSY at all.

volatile bool strobe_detect = false;
volatile bool error         = false;
static void __not_in_flash_func(strobe_callback)()
{
        gpio_put(busy_pin, 1);
        gpio_put(DEBUG0_PIN, 1);

        uint8_t d = get_data();
        multicore_fifo_push_blocking(d);
        checksum += d;
        ++nr_bytes;

        gpio_put(busy_pin, 0);

        // Pulse ACK low.
        gpio_put(n_ack_pin, 0);
        sleep_us(ACK_DURATION_US);
        gpio_put(n_ack_pin, 1);

        gpio_put(DEBUG0_PIN, 0);
        gpio_acknowledge_irq(n_strobe_pin, GPIO_IRQ_EDGE_FALL);
}

void core1_main()
{
    setup_ios();

    irq_set_exclusive_handler(IO_IRQ_BANK0, strobe_callback);
    irq_set_enabled(IO_IRQ_BANK0, true);
    irq_set_priority(IO_IRQ_BANK0, PICO_HIGHEST_IRQ_PRIORITY);

    gpio_set_irq_enabled(n_strobe_pin, GPIO_IRQ_EDGE_FALL, true);
    gpio_set_irq_enabled(n_strobe_pin, GPIO_IRQ_EDGE_RISE, false);
}

int main() {
    stdio_init_all();
    stdio_set_translate_crlf(&stdio_usb, false);

    multicore_launch_core1(core1_main);

    while(1){
        uint8_t c = multicore_fifo_pop_blocking();
        putchar(c);

        // Plugging in the jumper prints this out this debug information.
        // If you do this while the host is printing, the print data will
        // be corrupted..
        if (gpio_get(jumper_pin) == 0){
            printf("sum: %d, nr_bytes: %d\n", checksum, nr_bytes);
            checksum = 0;
            nr_bytes = 0;

            // These delays are a crude debounce...
            sleep_ms(200);
            while(gpio_get(jumper_pin) == 0)
                ;
            sleep_ms(200);
        }
    }
}

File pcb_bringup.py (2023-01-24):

# Micropython script to bring up PCV v1.

import board
import digitalio
import time
import supervisor

supervisor.disable_autoreload()

#if False:
#    f = open("test.log", "a")
#    f.write("Hello world!")
#    f.close()

led = digitalio.DigitalInOut(board.LED)
led.direction = digitalio.Direction.OUTPUT

test_pin = digitalio.DigitalInOut(board.GP0)
test_pin.direction = digitalio.Direction.OUTPUT

# high_drive. When 1, outputs are in totem-pole mode, otherwise
# they are in open-drain mode.
hd_pin = digitalio.DigitalInOut(board.GP17)
hd_pin.direction = digitalio.Direction.OUTPUT
hd_pin.value = False

# direction: when high, then direction is from connector to Pico
dir_pin = digitalio.DigitalInOut(board.GP16)
dir_pin.direction = digitalio.Direction.OUTPUT

# For now, test other direction...
dir_pin.value = False

#============================================================
# Control: from host to printer
#============================================================
strobe_pin = digitalio.DigitalInOut(board.GP15)
strobe_pin.direction = digitalio.Direction.INPUT

autof_pin = digitalio.DigitalInOut(board.GP14)
autof_pin.direction = digitalio.Direction.INPUT

init_pin = digitalio.DigitalInOut(board.GP13)
init_pin.direction = digitalio.Direction.INPUT

selin_pin = digitalio.DigitalInOut(board.GP12)
selin_pin.direction = digitalio.Direction.INPUT

#============================================================
# Data: from host to printer
#============================================================

d0_pin = digitalio.DigitalInOut(board.GP11)
d0_pin.direction = digitalio.Direction.INPUT

d1_pin = digitalio.DigitalInOut(board.GP10)
d1_pin.direction = digitalio.Direction.INPUT

d2_pin = digitalio.DigitalInOut(board.GP9)
d2_pin.direction = digitalio.Direction.INPUT

d3_pin = digitalio.DigitalInOut(board.GP8)
d3_pin.direction = digitalio.Direction.INPUT

d4_pin = digitalio.DigitalInOut(board.GP7)
d4_pin.direction = digitalio.Direction.INPUT

d5_pin = digitalio.DigitalInOut(board.GP6)
d5_pin.direction = digitalio.Direction.INPUT

d6_pin = digitalio.DigitalInOut(board.GP5)
d6_pin.direction = digitalio.Direction.INPUT

d7_pin = digitalio.DigitalInOut(board.GP4)
d7_pin.direction = digitalio.Direction.INPUT

#============================================================
# Status: from printer to host
#============================================================
error_pin = digitalio.DigitalInOut(board.GP22)
error_pin.direction = digitalio.Direction.OUTPUT
error_pin.value = False

ack_pin = digitalio.DigitalInOut(board.GP21)
ack_pin.direction = digitalio.Direction.OUTPUT
ack_pin.value   = True

busy_pin = digitalio.DigitalInOut(board.GP20)
busy_pin.direction = digitalio.Direction.OUTPUT
busy_pin.value  = False

pe_pin = digitalio.DigitalInOut(board.GP19)
pe_pin.direction = digitalio.Direction.OUTPUT
pe_pin.value    = True

sel_pin = digitalio.DigitalInOut(board.GP18)
sel_pin.direction = digitalio.Direction.OUTPUT
sel_pin.value   = True

all_inputs = [ d0_pin, d1_pin, d2_pin, d3_pin, d4_pin, d5_pin, d6_pin, d7_pin, strobe_pin, autof_pin, init_pin, selin_pin ]

def test_inputs():
    val = 0
    for i in all_inputs:
        val = (val << 1) | i.value

    print(f"%04x" % (val))

if False:
    led.value = False
    print("1")
    time.sleep(1)
    led.value = True
    print("2")
    time.sleep(1)
    led.value = False
    print("3")
    time.sleep(1)
    led.value = True
    print("4")
   
while False:
    led.value           = True
    test_pin.value      = True
    sel_pin.value       = True
    time.sleep(1)
    test_inputs()
    led.value           = False
    test_pin.value      = False
    sel_pin.value       = False
    time.sleep(1)
    test_inputs()
    pass

def get_data():
    b = ((((((((((((((
            d7_pin.value) << 1) | 
            d6_pin.value) << 1) | 
            d5_pin.value) << 1) | 
            d4_pin.value) << 1) | 
            d3_pin.value) << 1) | 
            d2_pin.value) << 1) | 
            d1_pin.value) << 1) | d0_pin.value

    return b

sel_pin.value   = True
pe_pin.value    = False
ack_pin.value   = True
busy_pin.value  = False
error_pin.value = False

print("Listening...")

time.sleep(0.5)
ack_pin.value   = False
busy_pin.value  = True
error_pin.value  = True
time.sleep(0.5)
ack_pin.value   = True
busy_pin.value  = False
error_pin.value  = True

pe_pin.value = False
error_pin.value  = True

while True:
    print(f"nStrobe: %d, nAUTOF: %d, nINIT: %d, nSELIN: %d, data: %d" % 
            (strobe_pin.value, autof_pin.value, init_pin.value, selin_pin.value, get_data()))

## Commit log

2022-12-31 PCB v1 complete.
    [Pico.skp, Test.kicad_pcb, Test.kicad_sch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]
2023-01-01 Design with 74LVC161284.
    [parallel2usb-B_Cu.gbr, parallel2usb-B_Mask.gbr, parallel2usb-B_Paste.gbr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]
2023-01-15 IRQ handler that is too slow.
    [main.cc]
2023-01-15 Grabs bytes successfully from printer port.
2023-01-15 Example traces.
2023-01-16 spectrum analyzer printer port traces.
2023-01-17 PCB v2.
    [Pico.skp, Test.kicad_pcb, Test.kicad_sch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]
2023-01-19 Minor schematic and gerber updates.
    [parallel2usb-B_Cu.gbr, parallel2usb-B_Mask.gbr, parallel2usb-B_Paste.gbr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]
2023-01-21 Add comments about board revision check.
2023-01-24 pcb_bringup.py script.
2023-01-24 r3273 captured traces.
2023-03-19 Move printer data capturing to core1.
2024-04-04 README: add a more reliable conversion flow for EPS
    Inkscape sometimes pops up interactive windows when you try to import EPS, and the command line arguments to Inkscape keep changing. If you just want to rasterize, use Ghostscript as a rasterizer.
